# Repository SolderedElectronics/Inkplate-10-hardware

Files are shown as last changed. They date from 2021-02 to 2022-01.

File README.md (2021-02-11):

# Inkplate 10 Open Source Hardware files



Open Source Hardware (OSH) files for e-paper display Inkplate 10 can be found in this repo. Inkplate 10 is a powerful, Wi-Fi enabled ESP32 based nine-point-seven-inch e-paper display – recycled from a Kindle e-reader. Its main feature is simplicity. Just plug in a USB cable, open Arduino IDE/micropython/ESP-IDF, and change the contents of the screen with few lines of code. Learn more about Inkplate 10 on [Crowd Supply](https://www.crowdsupply.com/e-radionica/inkplate-10) or [official website](https://inkplate.io).

### Versions:
- v1.0. first, original version shipped to backers in 2021

### Misc
Inkplate 10 is available for purchase via:
- [e-radionica.com](https://e-radionica.com/en/inkplate.html)
- [Crowd Supply](https://www.crowdsupply.com/e-radionica/inkplate-10)

For all questions and issues, please open an issue or thread on [our forums](http://forum.e-radionica.com/en/).
For sales & collaboration, please reach us via [e-mail](mailto:kontakt@e-radionica.com).

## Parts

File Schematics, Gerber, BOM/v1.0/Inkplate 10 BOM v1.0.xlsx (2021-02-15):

Comment | Description | Designator | Footprint | LibRef | Quantity | Dostupno / naručeno
4u7-TMK212AB7475KG-T |  | C1, C2, C3, C4, C5, C6, C8, C10, C11, C12 | 0805C | 0805C | 10
10uF-GRM188R61E106KA73J |  | C7, C9, C13 | 0603C | 0603C | 3
100nF - AC0603KRX7R8BB104 |  | C14, C15 | 0603C | 0603C | 2
10nF-AC0603KRX7R8BB103 |  | C16, C17 | 0603C | 0603C | 2
2u2-GRM188R61E225MA12D |  | C18, C19 | 0603C | 0603C | 2
10uF |  | C20, C39, C46 | 1206C | 1206C | 3
2u2 |  | C21, C33, C36, C38, C54 | 0603C | 0603C | 5
100nF |  | C22, C23, C24, C26, C27, C28, C30, C34, C35, C37, C40, C41, C45, C47, C48, C49, C50, C55, C56 | 0603C | 0603C | 19
DNP |  | C25, C32 | 2917C | 2917C | 2
2.2uF |  | C29 | 0603C | 0603C | 1
100pF |  | C31 | 0603C | 0603C | 1
1uF |  | C42 | 0603C | 0603C | 1
12pF |  | C43, C44 | 0603C | 0603C | 2
27pF |  | C51, C52, C53 | 0603C | 0603C | 3
BAS3010S-02LRHE6327 | BAS3010S-02LRHE6327 | D1 | BAS3010S-02LRHE6327 | DIODE SCHOTTKY 30V 1A TSLP-2 | 1
DIODE SCHOTTKY 30V 1A TSLP-2 | BAS3010S-02LRHE6327 | D2 | BAS3010S-02LRHE6327 | DIODE SCHOTTKY 30V 1A TSLP-2 | 1
BAT54-SOT23 | SINGLE SHOTTKY DIODE | D3, D4, D5, D6 | SOT-23-3 | BAT54-SOT23 | 4
GREEN |  | D7 | 0603LED | 0603LED | 1
BAT20J |  | D8 | SOD-323 | BAT20J | 1
DIODA M4 |  | D9, D10 | DIODA SMA | DIODA M4 | 2
LTST-S270TBKT |  | D11 | 0603 Side view LED LTST-S270GKT | 0603LED_side view | 1
1206FUSE_500mA |  | F1 | 1206FUSE | 1206FUSE | 1
2/3 pads connected |  | JP1, JP2, JP3, JP7 | SMD_JUMPER 2/3 pads | SMD_JUMPER 2/3 pads connected | 4
left connection |  | JP4, JP5, JP6 | SMD_JUMPER 2/3 pads left connection | SMD_JUMPER 2/3 Left pad connected | 3
SFV33R-1STE9HLF | Inkplate | K20 | SFV33R-1STE9HLF | SFV33R-1STE9HLF | 1
HEADER 8x1 |  | K22, K25 | HEADER MALE 8x1 | HEADER 8x1 | 2
easyC SMD |  | K23 | EasyC connector | easyC SMD | 1
JST 2pin |  | K30 | JST 2PIN SMD | JST 2pin | 1
U262-161N-4BVC11 | Inkplate | K31 | U262-161N-4BVC11 | U262-161N-4BVC11 | 1
C70373 |  | K33 | C70373 | C70373 battery holder | 1
Inkplate_TP |  | K37 | Inkplate test header | Inkplate test header | 1
HYC77-TF09-200 | MicroSD Inkplate | K38 | HYC77-TF09-200 | HYC77-TF09-200 | 1
LQH44PN4R7MP0L | Inductor Power Chip Shielded Wirewound 4.7uH 20% 1MHz Ferrite 1.7A 96mOhm DCR 1515 Embossed T/R | L1 | LQH44PN4R7MP0_Inductor | LQH44PN4R7MP0L | 1
NR4012T2R2M | FIXED IND 2.2UH 1.2A 108 MOHM | L2 | NR4012T2R2M_Fixed Inductor | NR4012T2R2M | 1
PAD |  | PAD1, PAD2, PAD3, PAD4, PAD5, PAD6, PAD7, PAD8, PAD9 | PAD4x4 | PAD | 9
DNP |  | Q1 | SOT-23-3 | PMOS SOT-23-3 | 1
SN74LVC1G34DBV | Inkplate | Q2 | SOT-23-5 | SN74LVC1G34DBV | 1
MCP73831T |  | Q3 | SOT-23-5 | MCP73831T | 1
NPN |  | Q4, Q7, Q9 | SOT-23-3 | NPN SOT-23-3 | 3
PMOS |  | Q5, Q11 | SOT-23-3 | PMOS SOT-23-3 | 2
NMOS |  | Q6 | SOT-23-3 | NMOS SOT-23-3 | 1
SSM3J358R,LF |  | Q8, Q10 | SOT-23-3 | PMOS SOT-23-3 | 2
NTC-NCP18XH103F03RB |  | R1 | 0603R | 0603R | 1
43k-RC0603FR-0743KL |  | R2 | 0603R | 0603R | 1
10K |  | R3, R4, R16, R20, R27 | 0603R | 0603R | 5
1M |  | R5, R6 | 0603R | 0603R | 2
47k5-RC0603FR-0747K5L |  | R7 | 0603R | 0603R | 1
52k3-RC0603FR-0752K3L |  | R8 | 0603R | 0603R | 1
1K |  | R9, R14, R26, R30, R31, R33 | 0603R | 0603R | 6
0R |  | R10 | 0603R | 0603R | 1
DNP |  | R11, R22 | 0603R | 0603R | 2
470R |  | R12 | 0603R | 0603R | 1
330R |  | R13 | 0603R | 0603R | 1
510K |  | R15 | 0603R | 0603R | 1
2K49 |  | R17 | 0603R | 0603R | 1
5.1K |  | R18, R19 | 0603R | 0603R | 2
100K |  | R21, R23, R24, R25, R28, R29, R32, R34 | 0603R | 0603R | 8
Pushbutton SMD |  | S1 | Pushbutton SMD | Pushbutton SMD | 1
K2-1114SA-A4SW-06 | Inkplate | S2, S4 | K2-1114SA-A4SW-06 | Pushbutton K2-1114SA-A4SW-06 | 2
SK-3296S-01-L1 |  | S3 | SK-3296S-01-L1 | Switch SK-3296S-01-L1 | 1
TPS65186RGZR | IC PWR MGMT E INK 48VQFN | U1 | TPS65186_QFN_48 | TPS65186RGZR | 1
MCP23017T-E/SS |  | U2, U4 | SSOP-28 10.20x5.30mm | MCP23017_SS | 2
ESP32-WROVER |  | U3 | ESP32-WROVER | ESP32-WROVER | 1
TPS7A2633DRVR |  | U5 | TPS7A2633DRVR | TPS7A2633DRVR | 1
PCF85063ATL/1,118 |  | U6 | DFN-10 | PCF85063A | 1
CH340C |  | U7 | SOP-16 | CH340C | 1
MC14093BDTR2G | Inkplate | U8 | TSSOP14_MC14093B | MC14093BDTR2G | 1
TPS3840PL27DBVR |  | U9 | TPS3840PH30DBVR | TPS3840PH30DBVR | 1
TTP223E-BA6 |  | U10, U11, U12 | SOT-23-6 | TTP223E | 3
7LC32768F12UC |  | X1 | 3215Crystal | 3215Crystal | 1

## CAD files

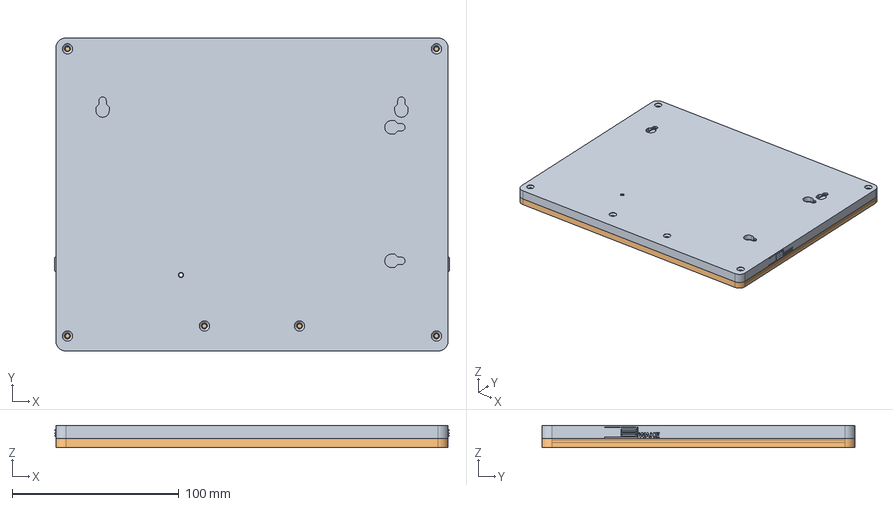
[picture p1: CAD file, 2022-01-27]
3D printable case/Original case/Inkplate10_Case_V1.6.step
236.6 x 187.5 x 13.2 mm
Inkplate10_Case_Bottom
Inkplate10_Case_Top
Inkplate10_Case_Top_Dots

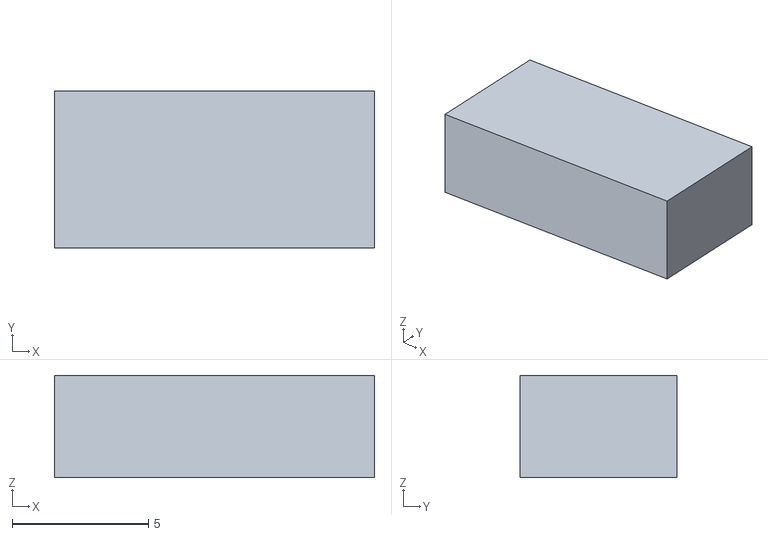
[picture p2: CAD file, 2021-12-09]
3D printable case/Original case/Inkplate 10 touch pads square.STL
11.8 x 5.75 x 3.75

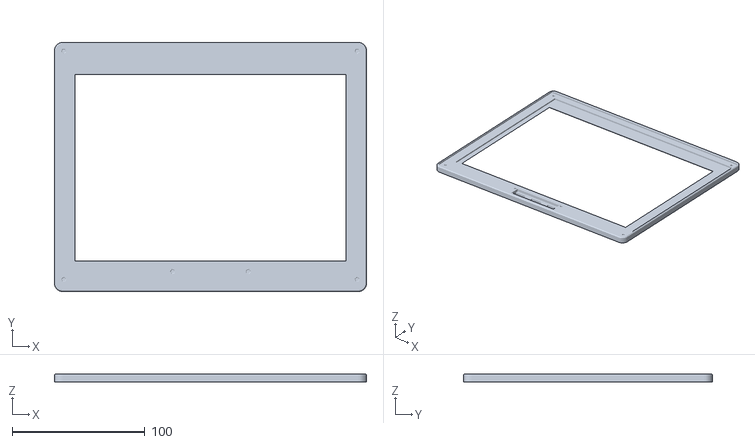
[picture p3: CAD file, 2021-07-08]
3D printable case/Original case/Inkplate10_Case_v1.6_Top.stl
235.0 x 187.5 x 6.20

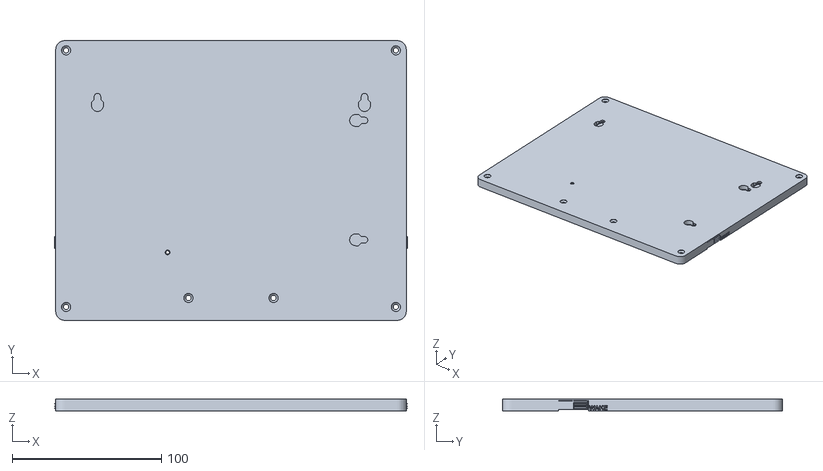
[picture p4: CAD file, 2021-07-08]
3D printable case/Original case/Inkplate10_Case_v1.6_Bottom.stl
236.6 x 187.5 x 7.80

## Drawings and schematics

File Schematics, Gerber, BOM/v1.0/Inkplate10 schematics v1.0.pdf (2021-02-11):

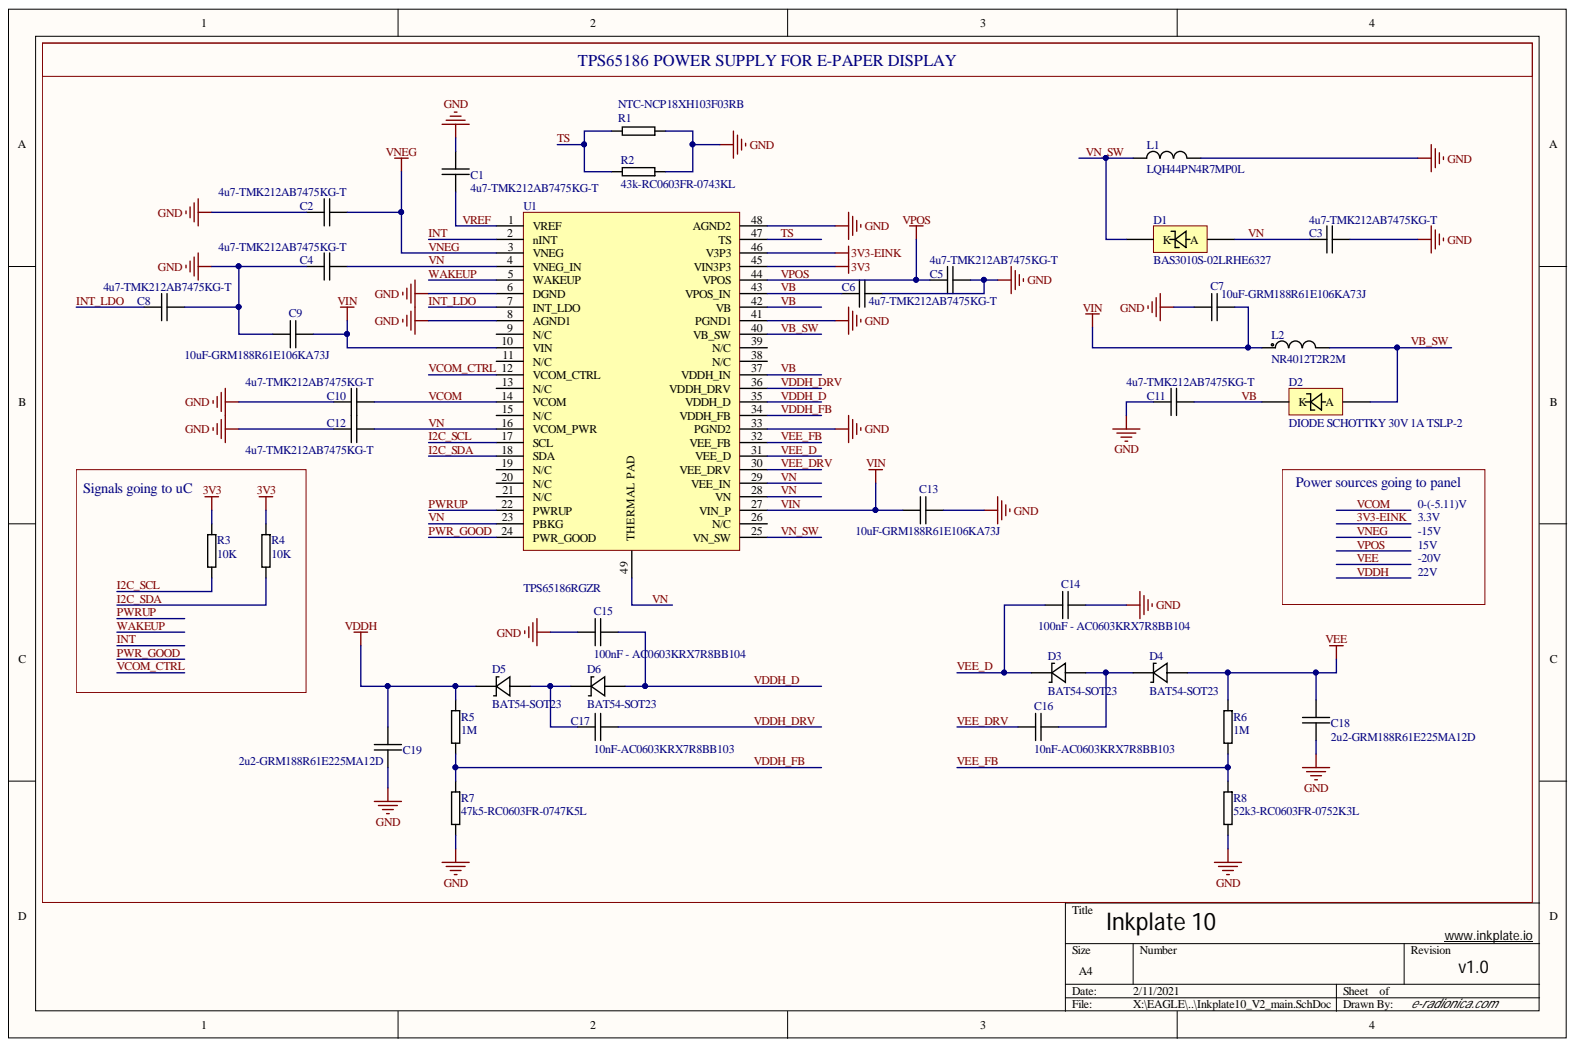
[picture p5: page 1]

TPS65186 POWER SUPPLY FOR E-PAPER DISPLAY

INT_LDO | INT_LDO 7 AGND1 8 | VB | VIN

Power sources going to panel

Signals going to uC

Size A4 | Number | Revision v1.0

Date: 2/11/2021 | Sheet of
File: X:\EAGLE\..\Inkplate10_V2_main.SchDoc | Drawn By: e-radionica.com

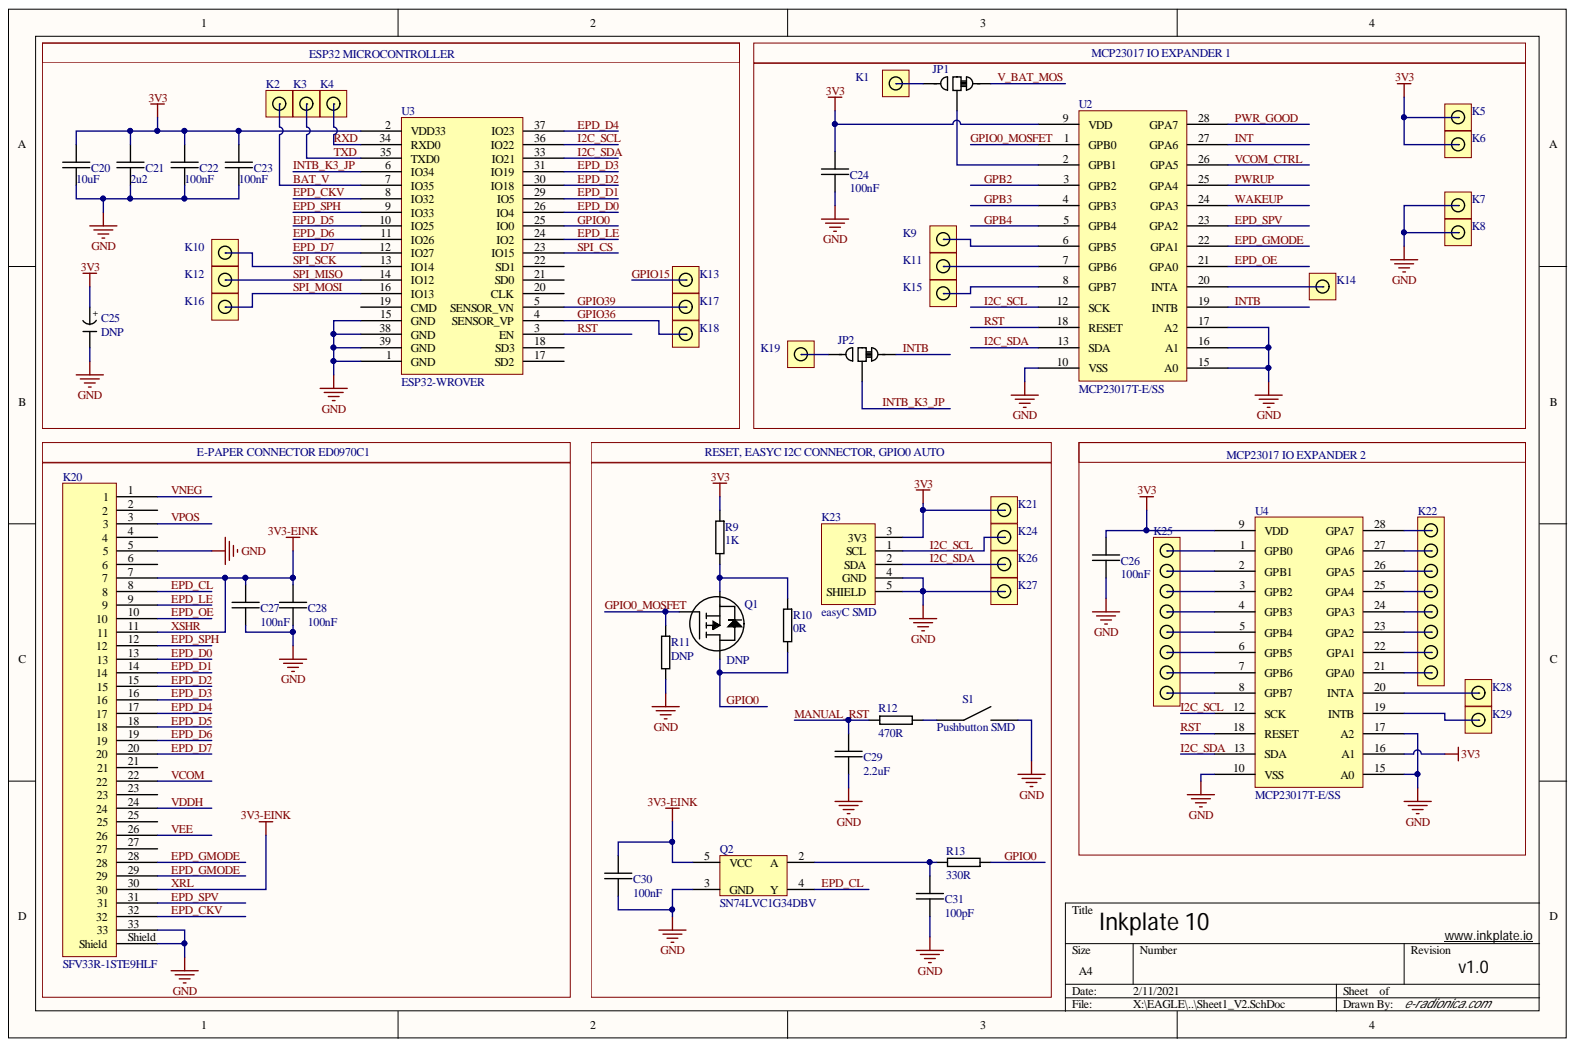
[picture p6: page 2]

RESET, EASYC I2C CONNECTOR, GPIO0 AUTO

I2C_SCL

I2C_SCL | GPB0 1 GPB1 2 GPB2 3 GPB3 4 GPB4 5 GPB5 6 GPB6 7 GPB7 8 SCK 12

Size A4 | Number | Revision v1.0

Date: 2/11/2021 | Sheet of
File: X:\EAGLE\..\Sheet1_V2.SchDoc | Drawn By: e-radionica.com

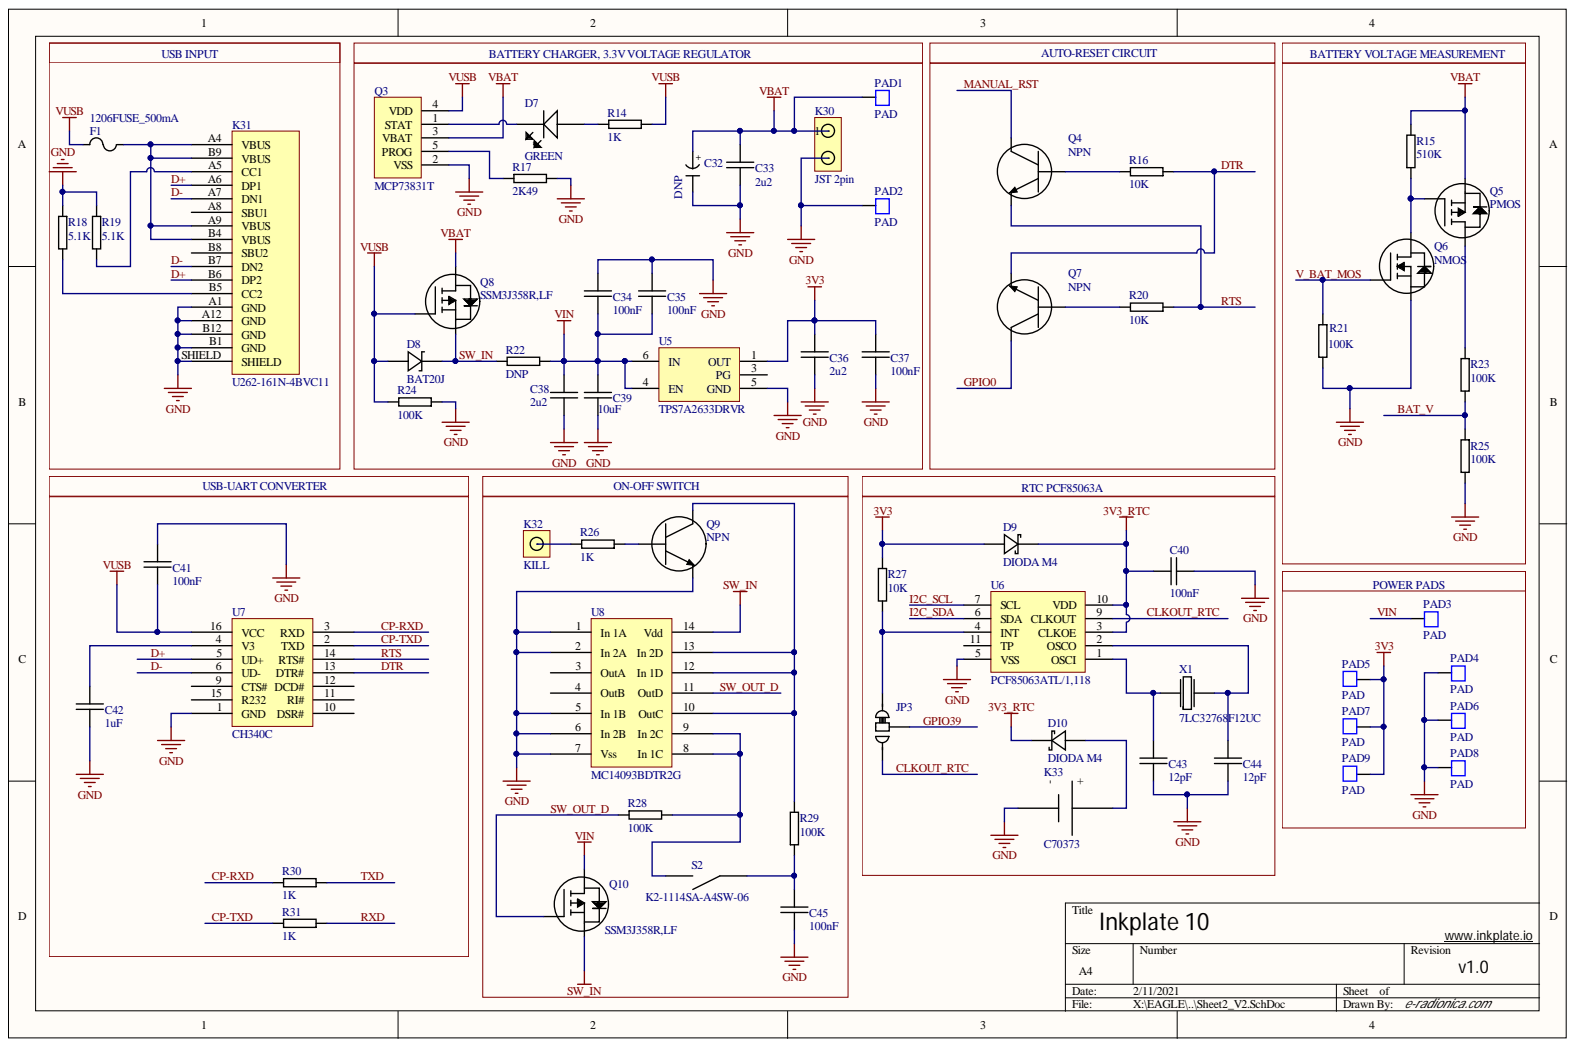
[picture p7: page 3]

BATTERY CHARGER, 3.3V VOLTAGE REGULATOR

VBUS B4

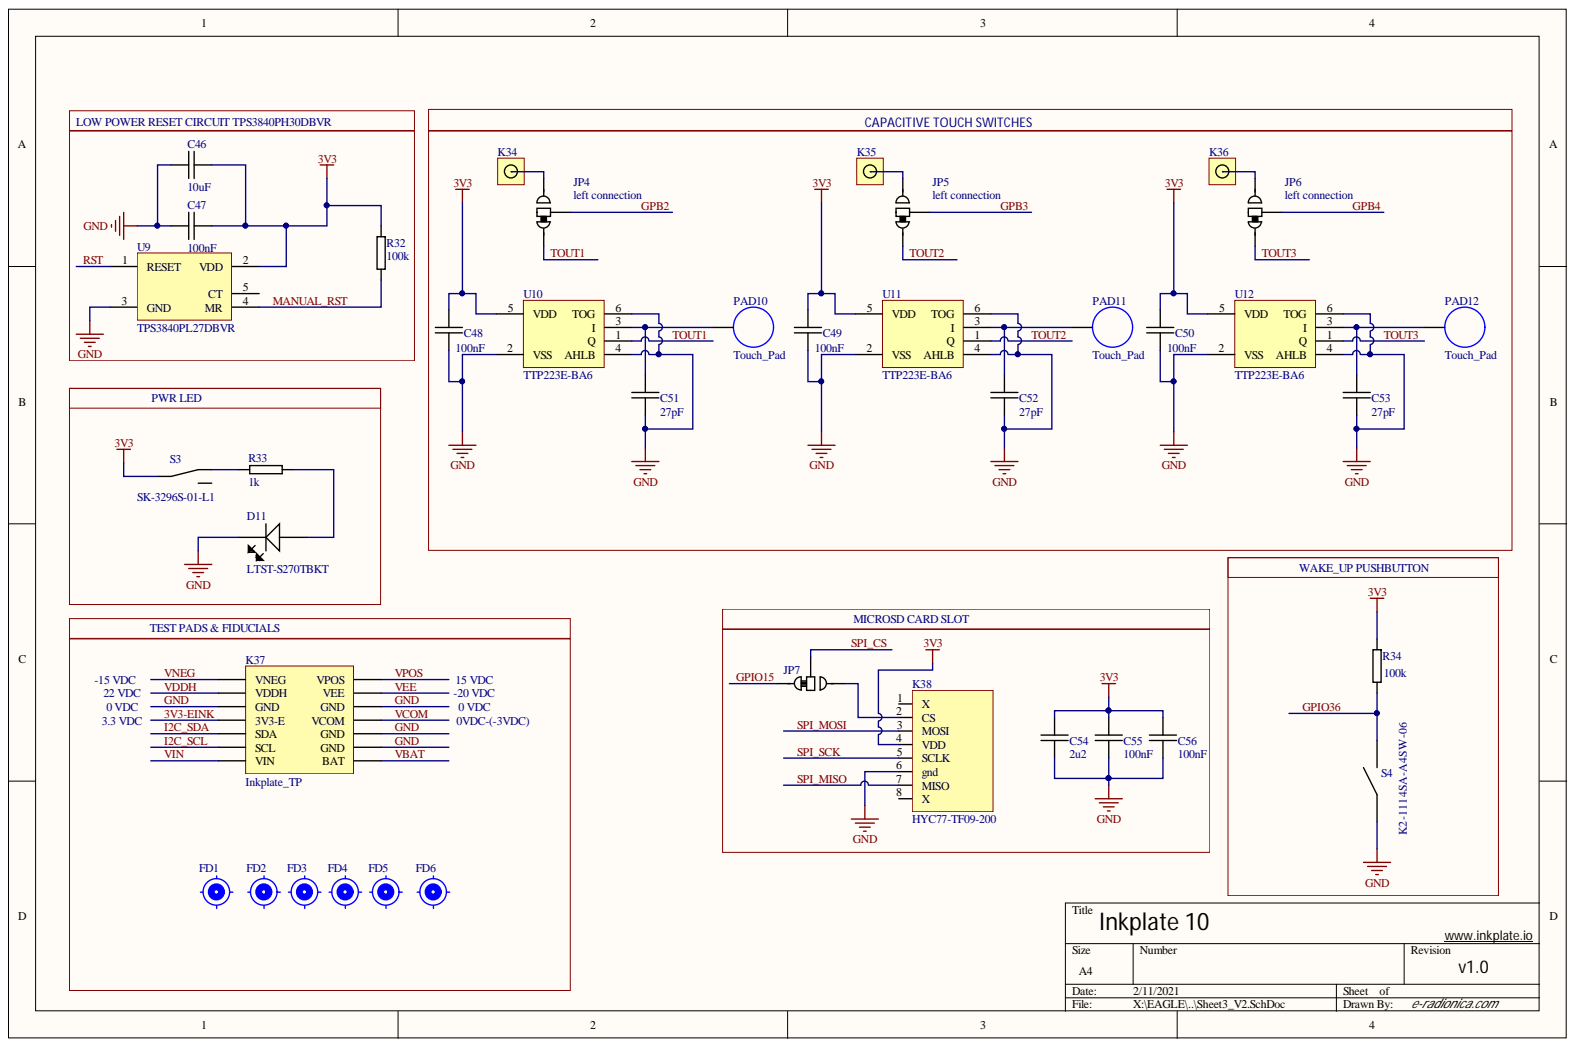
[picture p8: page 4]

LOW POWER RESET CIRCUIT TPS3840PH30DBVR

Size A4 | Number | Revision v1.0

Date: 2/11/2021 | Sheet of
File: X:\EAGLE\..\Sheet3_V2.SchDoc | Drawn By: e-radionica.com

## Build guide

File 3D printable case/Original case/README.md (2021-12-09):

3D printable case. Can fit Prusa MK3S(+) bed. Printed in [PLA Space](https://e-radionica.com/en/e-radionica-com-special-filament-1-75mm-space.html).

Screws: M3 x 10mm countersunk, 6 pieces, any head (HEX prefferable)

For touch pads squres, print of any material and add conductive tape around it. Afterwards, place them into the enclosure.

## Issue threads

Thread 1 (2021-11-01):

Unexpected reboot by ESP32 rush current with external circuit

pasutisu, 2021-11-01:
## Environment
* Inkplate 10
* external circuit require 3.3V/<200mA power supply from Inkplate 10

## Repro Steps
1. Connect external circuit and Inkplate 10.
2. Boot Inkplate 10.
3. Execute code that booting Wi-Fi logic like `WiFi.status()`.
4. Sometimes reboot without any error message.

## Reason I thought
* ESP32 has 500mA+ rush current on booting Wi-Fi.
* This board using TPS7A26 series supply only 500mA.

## Solution I tried
* I added a 470uF capasitor to 3.3V line near ESP32, it works well.

BornaBiro, 2021-11-02:
What kind of power supply is used for the Inkplate board? Too weak power supply can cause problems, as Inkplate itself can consume 500mA while refreshing the panel and connecting to WiFi (mostly in a form of current spikes), so there is not much left for external circuits. Adding a capacitors on 3.3V rail can help with maintaining constant voltage as they can serve as a "energy storage" during current spikes.

pasutisu, 2021-11-02:
I tried to supply 5V/900mA and 5V/2A to Inkplate 10 (5V/2A was more stably a bit).

I understood that if I use my circuit with Inkplate 10 stably, I need to add a LDO or caps from your comment.
But I hope more powerful LDO to 3.3V line in next version!

Thanks for helping me :)

Closed 2021-11-02.

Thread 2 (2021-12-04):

STL files for Inkplate 10 are not the same size.

jf1452, 2021-12-04:
I just printed the stl for the Top of the case, the cavity for the PCB is 1mm to short in the x direction, and very tight in the y direction.
I compared the stls for top and bottom and are both different dimensions. Top is 1mm shorter than bottom.
I've just scaled top to get the extra 1mm back and just started printing again.
Can you correct the STLs and even better, add the source files?

davidzovko, 2021-12-05:
Hi, that difference should be on purpose :) we have printed 100's of those and all fitted without errors. Is it possibly due to the printer tolerance? This if the first time someone reports it as well, and we have had many people print on their own as well.

I will check for the source files and add them!

jf1452, 2021-12-05:
Great, re-printed the top at 101% and got a good fit; now waiting for the bottom to finish (not rescaled); noticed it has a lip so probably going to fail.
I'm now using an Ender 5 plus, never had any scaling issues before so will recheck against the cura slice and part measurements.

davidzovko, 2021-12-06:
Let me know if that worked for you in the end!

jf1452, 2021-12-07:
Reset my printer. Full recheck squareness of printer axis; I've fixed a skew issue where the Y-Axis was not quite true to the frame; now got perfect right angles.
I've printed the STLs again, cavity for the PCB is 230.52mm x 180.42mm which looks good; your spec says PCB is 230x180 so should be a good fit. After loading the STL into FreeCAD, dimensions seem to agree.
PCB I received from Crowdsupply and soldered.com is 231.25mm x 180.46mm.
3D printer is now definitely correct; but the PCB is slightly too large.

davidzovko, 2021-12-09:
Hi, the design is already pretty "loose" so even uncalibrated printed should work. To be honest, I am not sure how can you measure to 1/10 of the millimeter using hand measurement tools? :)

Anyway, glad to got it working for you!

jf1452, 2021-12-10:
Printer is very well calibrated now better than +/- 0.2%

300mm Verniers are quite reasonably priced, measuring to better than 0.1mm is easy enough; 300mm Vernier is a must have if you have large 3D printers. Cheap ones can be bought from your favourite  sites from €30..

Also, it helps if you work for a company which makes measuring equipment that can achieve nm of resolution and 10's nm of accuracy :).  Helps you to avoid the common measuring mistakes.

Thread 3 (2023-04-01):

Case does not fit current model

werdnum, 2023-04-01:
I had a replacement Inkplate shipped to me recently because the original one was missing a charger IC. The new one seems to be physically smaller, and lack touchpads. I don't care a great deal about the touchpads, but the new smaller design seems to not fit in the 3D printable case.

The one I received is 225x162mm total, and has 4 M3x7mm standoffs in the corners. Happily this means that I should be able to print a case on my Ender 3 once I figure out a design.

Hopefully somebody (maybe I'll get around to it) will be able to redesign the case to fit the new dimensions.

KarloLeksic, 2023-04-04:
Hello,

We will publish the files so that everyone will have access to the cases that we print for Inkplates

werdnum, 2023-04-21:
> Hello,
>
> We will publish the files so that everyone will have access to the cases that we print for Inkplates

Fantastic! Any updates on this?

KarloLeksic, 2023-04-25:
Sorry, this may take a while.

But here are the attached files so you can print them:
[3D printable files.zip](https://github.com/SolderedElectronics/Inkplate-10-hardware/files/11322908/3D.printable.files.zip)

rsoric, 2023-07-20:
Closing the issue as my colleague has attached the required files

Closed 2023-07-20.

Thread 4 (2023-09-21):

inkplate10 latest version enclosure

dcolens, 2023-09-21:
the version of inkplate 10 I received does not have touchpads like described on this repo, could you share the enclosure STLs for this version too?

rsoric, 2023-09-21:
Hi @dcolens , just noted that the repository hasn't been updated yet but here's the files you need for the new version

[inkplate10_case_stl_files.zip](https://github.com/SolderedElectronics/Inkplate-10-hardware/files/12683693/inkplate10_case_stl_files.zip)

dcolens, 2023-09-21:
Thanks for the prompt reply :-)

Closed 2023-09-22.

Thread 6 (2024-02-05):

Reproducing assembled board requires cpl

johnholl, 2024-02-05:
Hi, I'm trying to have this board printed and assemble through JLCPBC (https://jlcpcb.com/). However, in addition to the Gerber and BOM files, they need a CPL file to determine placement of components on the board. I don't have much CAD experience, but my understanding is this can be generated from the original CAD files. Would you be able to generate and add the cpl file to this repo, or point me in the direction of how to produce my own from the existing files in the repo?

rsoric, 2024-02-12:
Hi @johnholl ,

@ifadiga , can you help out with this?

ifadiga, 2024-02-12:
Hi,

We have continued the conversation via email, and we are resolving this matter there.

Closed 2024-02-12.

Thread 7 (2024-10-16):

3D Print files don't fit my inkplate 10 from soldered

raphael303, 2024-10-16:
I have an Inkplate 10 from soldered and I printed the bottom of the case here on github, this doesn't fit at all. I have ordered the inkplate 10 together with the case in black, the one who came with it works well and is overall a bit smaller than the one I just printed.

The PCB is on little stands which are bolted to the PCB, not screwed. There is no way it fits the printed one. The holes are completely misaligned. There must be some other versions around, some older 3D print files too probably.

Has anybody here any idea about different versions of the case and the PCB?

rsoric, 2024-10-16:
Hi @raphael303 ,

Could you check [this ](https://github.com/SolderedElectronics/Soldered-Inkplate-10-hardware-design)repository which contains files for the newer version of Inkplate (labeled 'Soldered' Inkplate). If your PCB is purple - it's more than likely  the 'Soldered' newer version.

Do [these ](https://github.com/SolderedElectronics/Soldered-Inkplate-10-hardware-design/tree/main/OUTPUTS/V1.3.1/3D%20printable%20files) files work better for your device?

-Rob

raphael303, 2024-10-16:
Thank you. Looks better and I am printing now. A pitty for the filament wasted. To me it was not clear there were two versions, two repositories.

Closed 2024-10-17.

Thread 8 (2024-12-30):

How can I tell if the battery is charging?

werdnum, 2024-12-30:
Subject line says it all. I studied the schematics but it's not clear to me whether there's some way of finding out in software whether an Inkplate 10 is plugged in and/or charging.

rsoric, 2025-01-07:
Hi @werdnum ,

unfortunately, there is no digitalRead, distinctly saying yes/no to this, but you can make an accurate approximation via reading the battery voltage value. Through software, you can use [inkplate.readBattery()](https://github.com/SolderedElectronics/Inkplate-Arduino-library/blob/2dd263f2f9548aadac8638413a143beddf068a64/src/include/System.cpp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) to read the voltage of the battery. If Inkplate is charging (plugged in via USB) it will read a specific value, which varies model-to-model. Please measure this value on your device while charging and note it. Then, in code if you want to know if the device is charging or not, read the battery's voltage and if it's the noted value or really close to it, you're charging. This is an experimental approach, as there is no better way this is what I can suggest.

Hope it's useful!

-Rob

Closed 2025-01-07.

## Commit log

2021-02-11 Add v1.0 files
    [Inkplate 10 BOM final v1.0.xlsx, Inkplate10_Case_v1.1_Bottom.stl, Inkplate10_Case_v1.1_Top.stl]
2021-02-15 Update step, gerber and BOM files
    [Inkplate 10 BOM final v1.0.xlsx, Inkplate 10 BOM v1.0.xlsx]
2021-07-08 Added latest version of inkplate 10 case
    [Inkplate10_Case_v1.1_Bottom.stl, Inkplate10_Case_v1.1_Top.stl, Inkplate10_Case_v1.6_Bottom.stl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]
